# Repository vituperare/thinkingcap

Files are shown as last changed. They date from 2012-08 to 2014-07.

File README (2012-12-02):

The Thinking Cap v1.0 is the first major release of Grindhouse Wet Wares' implementation of the 
tDCS (transcranial Direct Current Stimulation and CES (Cranial Electrotherapy Stimulation)
concepts.  The idea is to stimulate your brain with direct current (in the case of tDCS)
or with square waves of current (in the case of CES) which can either raise or lower the
potential energy of the stimulated neurons, depending on the orientation of electrodes.
This allows them to fire more or less easily, and activates or deactivates a given region,
thus engaging certain brain states.

The code (included) is programmed to control an Arduino-compatible microcontroller to deliver
the necessary current.  It comes in the form of a library, so the hacker can choose his way of
controlling the current.  To create an instantiation of the ThinkingCap class, simply call the
"ThinkingCap" constructor, and then call the methods corresponding to the desired action.

The tDCS setting uses a current source and PWM to ramp up the current at the beginning, and ramp
it back down after a given stimulation time (20 minutes by default, but this setting is also
changeable).  The CES setting pulls a constant square wave, with a frequency to be set by the
user.

If the component values from the schematic are used, the current pulled should be roughly 0.5 mA
or less, but by changing these values, the current level can be manipulated.  However, pulling
currents in excess of 2 mA is not recommended for any use.

Thinking Cap v1.0 designed by ianmathwiz7; released 11-24-2012 by Grindhouse Wetware.

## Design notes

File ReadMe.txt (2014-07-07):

The Thinking Cap v1.0 is the first major release of Grindhouse Wet Wares' implementation of the 
tDCS (transcranial Direct Current Stimulation and CES (Cranial Electrotherapy Stimulation)
concepts.  The idea is to stimulate your brain with direct current (in the case of tDCS)
or with square waves of current (in the case of CES) which can either raise or lower the
potential energy of the stimulated neurons, depending on the orientation of electrodes.
This allows them to fire more or less easily, and activates or deactivates a given region,
thus engaging certain brain states.

The code (included) is programmed to control an Arduino-compatible microcontroller to deliver
the necessary current.  It comes in the form of a library, so the hacker can choose his way of
controlling the current.  To create an instantiation of the ThinkingCap class, simply call the
"ThinkingCap" constructor, and then call the methods corresponding to the desired action.

The tDCS setting uses a current source and PWM to ramp up the current at the beginning, and ramp
it back down after a given stimulation time (20 minutes by default, but this setting is also
changeable).  The CES setting pulls a constant square wave, with a frequency to be set by the
user.

If the component values from the schematic are used, the current pulled should be roughly 0.5 mA
or less, but by changing these values, the current level can be manipulated.  However, pulling
currents in excess of 2 mA is not recommended for any use.

The "software" folder contains the software necessary to control the Thinking Cap.  This consists
in an Arduino library called "thinkingcap" and a sample Arduino sketch called "TCexample.ino" that
imports this library.  The example code is designed to apply CES or tDCS depending on the position
of a switch, and to begin when a push-button is activated.

THe "hardware" folder contains gerber files, a bill of materials, and Eagle files necessary to create
a PCB for the Thinking Cap.  This is included within the "thinkingcap10a" folder; the "thinkingcap10b"
folder contains a design for a separate circuit that is not released nor recommended for use.

Thinking Cap v1.0 designed by ianmathwiz7; released 7-1-2013 by Grindhouse Wetware..

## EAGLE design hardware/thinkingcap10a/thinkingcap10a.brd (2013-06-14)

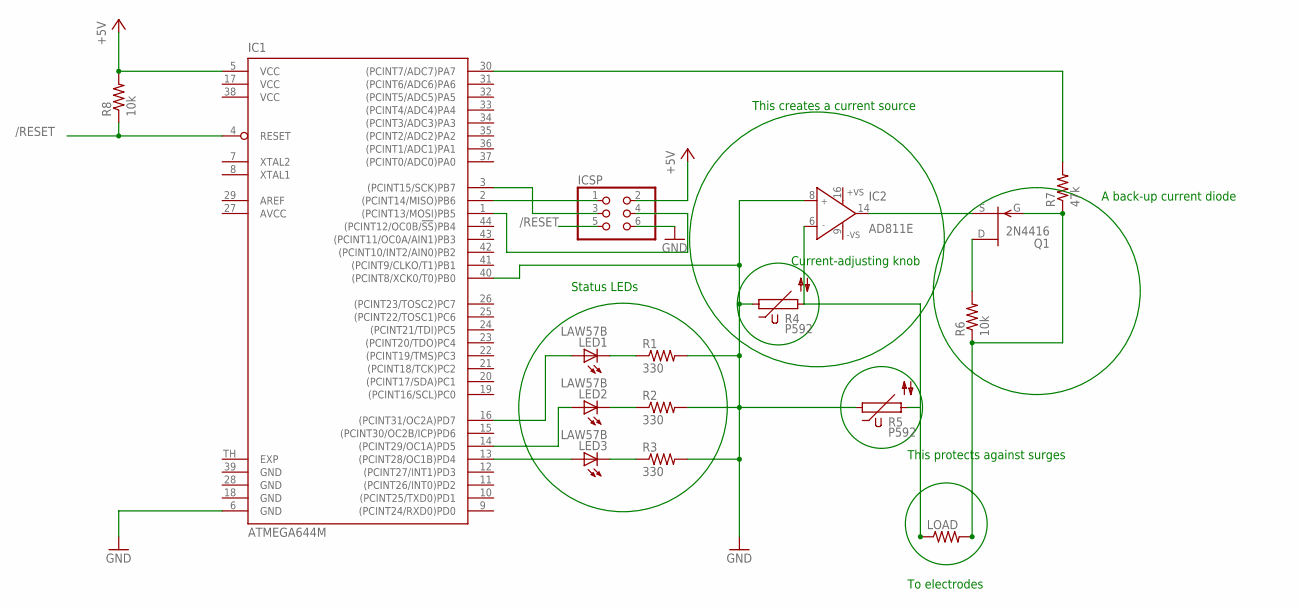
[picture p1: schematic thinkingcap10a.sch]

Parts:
IC1: ATMEGA644M; MLF44-TH
IC2: AD811E; PLCC20
ICSP: PINHD-2X3/90; 2X03/90
LED1, LED2, LED3: LAW57B; W57B
LOAD: R-US_0204/2V; 0204V
Q1: 2N4416; TO72
R1, R2, R3: 330; 0204V
R4, R5: P592
R6, R8: 10k; 0204V
R7: 47k; 0204V

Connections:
+5V: IC1.5 (VCC), ICSP.2, R8.2
/RESET: IC1.4 (RESET), ICSP.5, R8.1
AVCC: IC1.27 (AVCC)
EXP: IC1.TH (EXP)
GND: IC1.6 (GND), IC1.18 (GND), IC1.28 (GND), IC1.39 (GND), IC1.40 ((PCINT8/XCK0/T0)PB0), IC2.8 (IN+), ICSP.6, R1.2, R2.2, R3.2
unnamed: IC1.13 ((PCINT28/OC1B)PD4), LED3.A
unnamed: IC1.14 ((PCINT29/OC1A)PD5), LED2.A
unnamed: IC1.16 ((PCINT31/OC2A)PD7), LED1.A
unnamed: LED1.C, LED1.C@1 (C), LED1.C@2 (C), LED1.C@3 (C), LED1.C@4 (C), LED1.C@5 (C), R1.1
unnamed: LED2.C, LED2.C@1 (C), LED2.C@2 (C), LED2.C@3 (C), LED2.C@4 (C), LED2.C@5 (C), R2.1
unnamed: LED3.C, LED3.C@1 (C), LED3.C@2 (C), LED3.C@3 (C), LED3.C@4 (C), LED3.C@5 (C), R3.1
unnamed: IC1.2 ((PCINT14/MISO)PB6), ICSP.1
unnamed: IC2.6 (IN-), LOAD.1
unnamed: IC2.14 (OUT), Q1.1 (S)
unnamed: Q1.2 (D), R6.2
unnamed: IC1.30 ((PCINT7/ADC7)PA7), R7.2
unnamed: LOAD.2, Q1.3 (G), R6.1, R7.1
unnamed: IC1.3 ((PCINT15/SCK)PB7), ICSP.3
unnamed: IC1.1 ((PCINT13/MOSI)PB5), ICSP.4
VCC: IC1.17 (VCC), IC1.38 (VCC)

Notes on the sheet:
To electrodes
Status LEDs
This creates a current source
Current-adjusting knob
This protects against surges
A back-up current diode

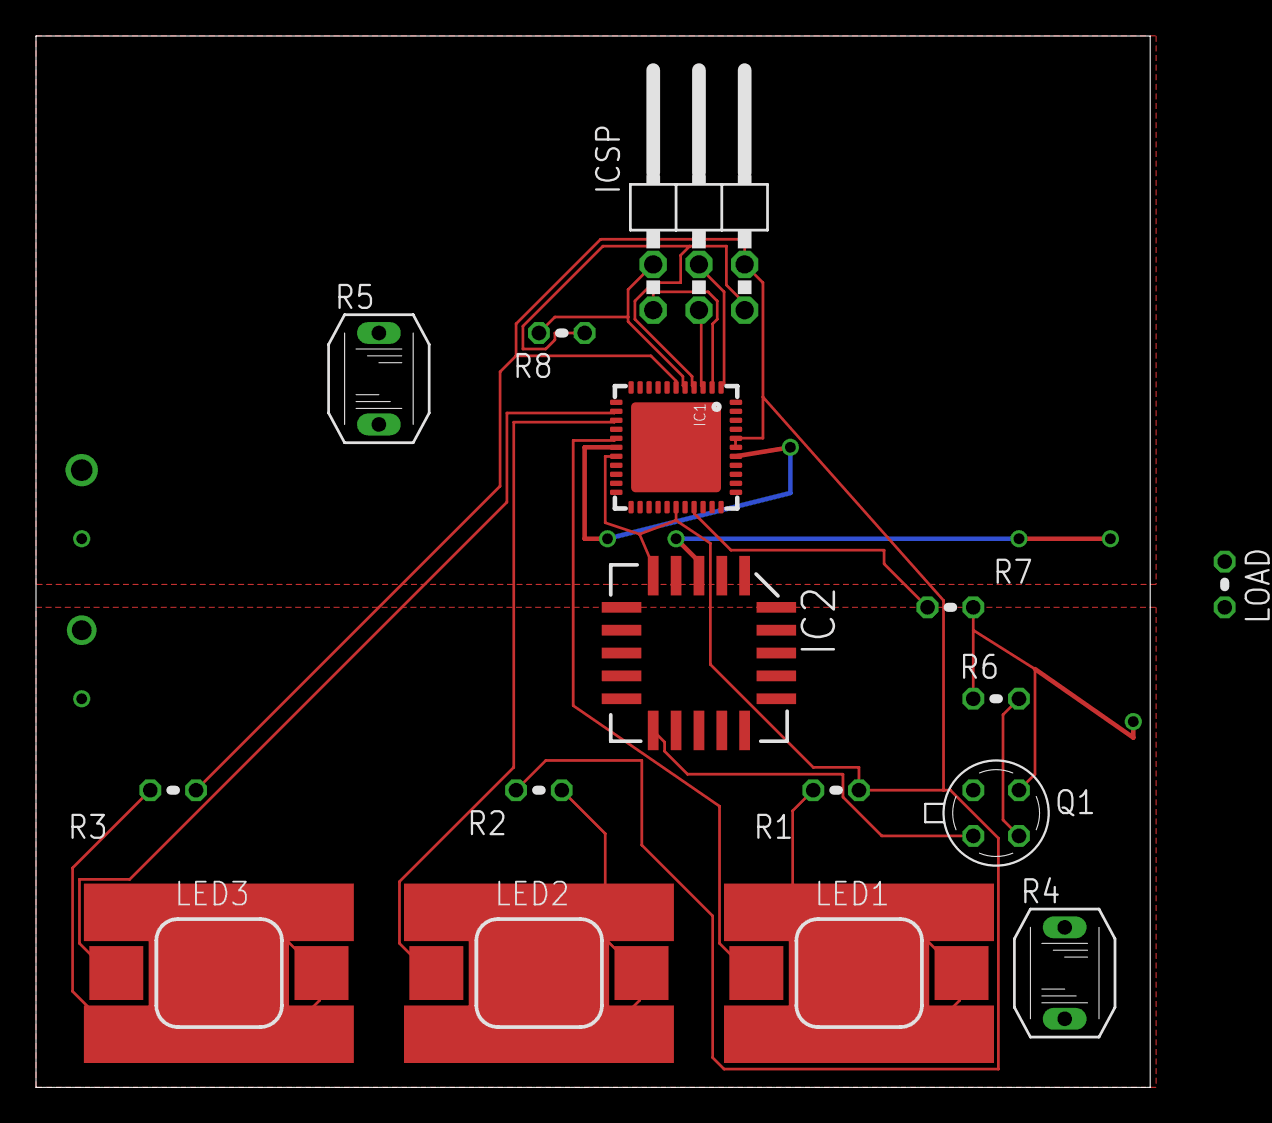
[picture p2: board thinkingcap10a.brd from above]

Board: 2 copper layers, 61.9 x 58.4 mm, 16 parts (0 on the bottom side), 18 nets.

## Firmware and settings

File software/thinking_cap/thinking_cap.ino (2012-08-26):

/*
Controls an Arduino to send current to a Thinking Cap (v0.1)
Uses pulse-width modulation to ramp average voltage up to 5 V, then keeps it going for 20 minutes
Warning:  Do not exceed 2 mA of current!  Ensure that the total resistance of your circuit is at least 2.5 kΩ
Written 2012 by ianmathwiz7, of Grindhouse Wetware (ianmathwiz7@gmail.com)
*/


int redpin = 13;      //Pin that controls the red light in the status LED
int greenpin = 12;    //Pin that controls the green light in the status LED
int bluepin = 11;     //Pin that controls the blue light in the status LED
int circuitpin = 10;  //Pin to which the electrode is attached
int timer = 0;        //Counts 20 minutes
int pwmtime = 10000;  //How long you want it to ramp
double maxpulse = 100;//Maximum pulse width

void setup()
{
  pinMode(circuitpin, OUTPUT);
  Serial.begin(9600);
  //Turn status LED yellow
  pinMode(greenpin, OUTPUT);
  pinMode(bluepin, OUTPUT);
  pinMode(redpin, OUTPUT);
  digitalWrite(greenpin, HIGH);
  digitalWrite(bluepin, HIGH);
}

void loop()
{
  //Check whether current is fully ramped
  
  int val = (int)millis()/1000.0;
  int pwmVal = map(val,0,30,0,255);
  if(val < 30)
  {
    //If it isn't, generate a square pulse
    analogWrite(circuitpin, pwmVal); 
  }
  else
  {
    //Otherwise, keep the current flowing and zero the timer
    digitalWrite(circuitpin, HIGH);
    timer = millis();
    //Turn status LED red
    digitalWrite(bluepin, LOW);
    digitalWrite(greenpin, LOW);
    digitalWrite(redpin, HIGH);
    Serial.println("The current is fully ramped; 20 minutes left");
    //While 20 minutes haven't passed
    while((millis() - timer) < 1200000)
    {
      //Serial.println("I'm in yr loop"); (used to help debug code, and kept for its pure hilariousness)
      //Every 30 seconds, print how much time is left
      if(!((millis() - timer) % 30000))
      {
        Serial.print(1200 - static_cast<double>(millis() - timer)/1000);
        Serial.println(" seconds left!");
      }
    }
    //After 20 minutes, print "time's up" and turn off current
    Serial.println("Time's up!");
    digitalWrite(circuitpin, LOW);
    digitalWrite(redpin, LOW);
    digitalWrite(greenpin, HIGH);
    for(;;) continue;
  }
  
}

double pulsewidth() //Gets the width of the pulse appropriate for the current time
{
  return maxpulse / pwmtime * millis();
}

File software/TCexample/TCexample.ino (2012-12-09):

#include <thinkingcap.h>

const int switchPin = 7;              //Connect a switch to pin 7
const int buttonPin = 6;              //Connect a spring-loaded push-button to pin 6
const int potentPin = A0;             //Connect a potentiometer to A0

boolean StartTC;                      //Stores whether or not the TC initialized successfully

ThinkingCap *tcap = new ThinkingCap(); //Default constructor; you can also pass arguments to it to set the pins

void setup()
{
  StartTC = (*tcap).begin();           //Prepares the Thinking Cap for use; also turns on the serial interface
  pinMode(switchPin, INPUT);
  pinMode(buttonPin, INPUT);
}

void loop()
{
  if(StartTC)                          //If the Thinking Cap setup was successful
  {
    if(digitalRead(buttonPin) == HIGH) //When the button is pushed
    {
      int potentVal = analogRead(potentPin);  //Get the value from the potentiometer
      if(digitalRead(switchPin) == HIGH) //If the switch is "on"
      {
        int time = map(potentVal, 0, 1023, 1, 60); //Convert the input value into a time
        (*tcap).tDCS(time / 2, time);  //Perform tDCS for that time, with ramp time equal to 1/120 of that
      }
      else                             //If the switch is "off"
      {
        while(digitalRead(buttonPin) == LOW)  //Until the button is pushed again
        {
          double freq = (double)map(potentVal, 0, 1023, 1, 500) / 100.0;  //Convert the input value into a frequency
          (*tcap).CES(freq);          //Perform CES with the given frequency
        }
      }
    }
  }
}

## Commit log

2012-08-27 Here is the current thinkingcap library, modified to accommodate Tim's suggestions, and also to make it run more cleanly.
2012-11-24 Added schematics (both the external release and the tMS prototype for internal release) and README file; performed final cleanup; v1.0 is officially ready for release!
2012-12-02 Added schematics and README for realz this time, because subversion is too lazy to do it automatically.
    [thinkingcap10a.sch, thinkingcap10b.sch]
2013-05-24 Updated SCH (a) to v1.0
    [thinkingcap10a.sch]
2013-06-14 Created PCB files; final draft for v1.0
    [thinkingcap10a.brd, thinkingcap10a.sch, thinkingcap10b.sch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]
